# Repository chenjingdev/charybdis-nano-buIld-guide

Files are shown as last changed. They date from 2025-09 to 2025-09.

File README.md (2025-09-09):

# Charybdis(카리브디스) 빌드/제작 가이드

이 레포에 흩어져 있던 가이드를 하나의 문서로 통합했습니다. 아래 목차에서 필요한 섹션을 찾아 읽으시면 됩니다. 원본 개별 문서는 그대로 두되, 상단에 본 README로의 안내 링크를 추가했습니다.

## 목차
- [부품 구매 리스트](#부품-구매-리스트)
- [PCB 설계도 및 출력](#pcb-설계도-및-출력)
  - [엄지/메인 PCB](#엄지메인-pcb)
  - [트랙볼 PCB](#트랙볼-pcb)
  - [C 포트 홀더(컨트롤보드 연결용)](#c-포트-홀더컨트롤보드-연결용)
  - [컨트롤보드(설계 참고)](#컨트롤보드설계-참고)

---

## 부품 구매 리스트

### PCB 주문 (JLCPCB 인보이스 기준)

| 보드 | 버전 | 수량(장) | 단가(USD) | 금액(USD) | 나노 1대 필요(장) |
|---|---|---:|---:|---:|---:|
| [Adapter (C 포트 홀더, 좌/우 세트)](https://github.com/Bastardkb/Elite-C-holder) | v2.1 | 5 | 0.80 | 4.00 | 1 |
| [Right (오른쪽 엄지)](https://github.com/Bastardkb/Charybdis-PCB-thumbs) | v2.01 | 5 | 0.80 | 4.00 | 1 |
| [Left (왼쪽 엄지)](https://github.com/Bastardkb/TBK-Mini-PCB-thumb-cluster) | v2.1 | 5 | 0.82 | 4.10 | 1 |
| [Main (메인)](https://github.com/Bastardkb/Skeletyl-PCB-plate) | v1.3 | 10 | 1.12 | 11.20 | 2 |
| [Sensor SMT (트랙볼 센서)](https://github.com/Bastardkb/charybdis-pmw-3360-sensor-pcb) | - | 5 | 4.74 | 23.68 | 1 |

- Merchandise: $46.98, Shipping: $11.74, Discount: -$9.00, Grand Total: $49.72

#### 출력 두께(주문 기준)
- Main(Y9): 0.8mm
- Left(Y12): 0.8mm
- Right(Y10): 0.8mm
- Adapter(Y4): 1.6mm
- Sensor PCBA(Y3): 1.6mm

### AliExpress 주문

| 부품명 | 옵션 명 | 1패키지당 부품수 | 패키지수량 | 총부품수 | 패키지가격 | 구매가격 | 나노 1대 필요 수량 |
|---|---|---:|---:|---:|---:|---:|---:|
| [SMD 칩 다층 세라믹 캐패시터, 1206 1UF, 50V, 100V, 200V, 105K, X7R, 10% 3216, 20 개 - AliExpress 502](https://www.aliexpress.com/item/1005007350273364.html) | 1206 1UF 50V | 20 | 3 | 60 | ₩1,546 | ₩1,546 | 2 |
| [100pcs SMD 다이오드 0805 SOD-123 1N5819 1N4007 1N4148 SOD123 SOD-323 1206 1N4148WS 1N5819WS B5819WS SOD323 쇼트키 다이오드 - AliExp](https://www.aliexpress.com/item/1005005707644429.html) | 1N4148W SOD123 | 100 | 3 | 300 | ₩1,988 | ₩1,988 | 40 |
| [10/50/100PCS 3.5mm 잭 여성용 오디오 커넥터 4 핀 DIP 헤드폰 잭 소켓 PJ-320A PJ320A 오디오 인터페이스 오디오 잭 검정색 - AliExpress 13](https://www.aliexpress.com/item/1005003111662179.html) | 100 Pcs | 100 | 1 | 100 | ₩8,260 | ₩8,260 | 2 |
| [마이크로 버튼 택트 스위치 Smd 4pin 3x4x2.5mm - 10pcs Smd 4x4x1.5 3mm 4 4 핀 촉각-Aliexpress](https://www.aliexpress.com/item/1005001291287576.html) | 4X4X1.5 Copper | 10 | 10 | 100 | ₩256 | ₩2,560 | 2 |
| [RP2040 Pro 마이크로 라즈베리 PI PICO 개발 보드 듀얼 코어는 Mciro Python을 지원합니다. - AliExpress 502](https://www.aliexpress.com/item/1005005980167753.html) | RP2040 Pro Micro 16M | 1 | 10 | 10 | ₩3,560 | ₩35,600 | 2 |
| [50pcs M1 M1.2 M1.4 M1.6 M2 M2.5 M3 M3.5 M4 GB819 미니 소형 검정색 탄소강 크로스 필립스 플랫 카운터 싱크 헤드 나사 볼트 - AliExpress 13](https://www.aliexpress.com/item/1005003205577232.html) | M3, 8mm | 50 | 10 | 500 | ₩1,155 | ₩11,550 | 3 |
| [50pcs M1 M1.2 M1.4 M1.6 M2 M2.5 M3 M3.5 M4 GB819 미니 소형 검정색 탄소강 크로스 필립스 플랫 카운터 싱크 헤드 나사 볼트 - AliExpress 13](https://www.aliexpress.com/item/1005003205577232.html) | M4, 8mm | 50 | 10 | 500 | ₩1,396 | ₩13,960 | 6 |
| [M2 M3 M4 M5 M6 M8 Brass Heat Insert Nut Double Twill Knurled Hot Melt Injection Embed Thread Inserts Nuts For 3d Printer](https://www.aliexpress.com/item/1005008666672949.html) | Length 5mm, M4 (OD6mm) 30pcs | 30 | 10 | 300 | ₩1,752 | ₩17,520 | 8 |
| [M2 M3 M4 M5 M6 M8 Brass Heat Insert Nut Double Twill Knurled Hot Melt Injection Embed Thread Inserts Nuts For 3d Printer](https://www.aliexpress.com/item/1005008666672949.html) | Length 5mm, M3 (OD5mm) 50pcs | 50 | 10 | 500 | ₩1,938 | ₩19,380 | 8 |
| [PMW3360DM-T2QU 및 LM19-LSI DIP PMW3360 PMW3360DM 센서, 렌즈 LM19 포함, 정품, 로트당 1 개 - AliExpress 502](https://www.aliexpress.com/item/4000904265601.html) | - | 1 | 5 | 5 | ₩9,900 | ₩49,500 | 1 |
| [SMD 픽셀 LED 칩, 개별 주소 지정 가능, 풀 컬러 DC 5V, SK6812 MINI-E RGB (WS2812B 유사), SK6812 3228, 100 개 - AliExpress 36](https://www.aliexpress.com/item/1005007863635868.html) | 100개 × 5 | 100 | 5 | 500 | ₩4,000 | ₩20,000 | 40 |
| [VEICHU 컨베이어 구성 요소 VCN310/311 스테인레스 스틸 라운드 내구성 황소 휠 전송 베어링 롤러 볼 - AliExpress 13](https://www.aliexpress.com/item/1005003066404497.html) | VCN310, 7.5 | 1 | 15 | 15 | ₩1,953 | ₩29,295 | 3 |
| [Perix303 트랙볼, 탈착식 마우스 트랙볼 570, 에르고 드로잉 마우스 볼, 사용자 정의 컴퓨터 게이머 액세서리 선물, 34mm - AliExpress 7](https://www.aliexpress.com/item/1005008358261130.html) | purpel Glossy | 1 | 1 | 1 | ₩28,650 | ₩28,650 | 1 |

### 네이버 주문 (케이블/소모품)

| 품목 | 옵션 명 | 패키지 단위 | 패키지가격 | 배송비 | 1대 필요량 | 1대 비용 |
|---|---|---:|---:|---:|---:|---:|
| [테프론 와이어 AWG26 (네이버 스토어)](https://smartstore.naver.com/spec/products/5320955211) | 단선, 100m, 검정 | 100m | ₩32,000 | ₩3,000 | 4m | ₩1,400 |
| [LT소재 희성납 유연납 RS60](https://smartstore.naver.com/scpmc/products/8570030651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) | 0.6mm, 500g 롤 | 500g | ₩24,000 | ₩3,000 | - | - |
| 필라멘트 (예: PLA) | 1kg 스풀 | 1kg | ₩30,000 | - | 0.33kg | ₩10,000 |

참고: 공식 설명서에서는 리본 케이블을 안내하지만 국내 조달이 어려워 위 테프론 AWG26 단선 케이블로 대체했습니다. 단선은 연선 대비 내구성이 높고 납땜이 쉬워 제작/유지보수에 유리했습니다.

### 스위치(선택 품목)

| 모델/링크 | 패키지 구성 | 패키지가격 | 나노 1대 필요 수량 | 1대 환산(참고) |
|---|---:|---:|---:|---:|
| [TTC Frozen V2 Linear 39g (110pcs)](https://www.aliexpress.com/item/1005008909952057.html) | 110개 | ₩49,990 | 40 | ₩18,178 |

---

### 나노 1대 예상 비용

- 부품 소계(KRW, 스위치 제외): ₩55,309  
  - LED 40개, RP2040 2개, 다이오드 40개, TRRS 커넥터 2개, 베어링/트랙볼 볼, 센서, 나사/인서트 등 포함  
  - 계산식: 각 행의 `(패키지가격 ÷ 1패키지당 부품수) × 나노 1대 필요 수량`
- 케이블 환산(KRW): ₩1,400 (100m/₩35,000 기준, 사용 4m)
- 필라멘트 환산(KRW): ₩10,000 (₩30,000/1kg 기준, 사용 0.33kg)
- 부품+케이블+필라멘트 소계(KRW, 스위치 제외): ₩66,709
- 스위치 환산(참고): ₩18,178 (위 선택 표 기준)
- 스위치 포함시 합계(KRW): ₩84,887
- PCB 소계(USD): $9.40  
  - Adapter $0.80 ×1, Right $0.80 ×1, Left $0.82 ×1, Main $1.12 ×2, Sensor $4.74 ×1

## PCB 설계도 및 출력

PCB 출력 공통 옵션: 거버 파일 업로드 후 색상만 변경. 그 외 옵션은 건드리지 않는 것을 권장합니다.

### 엄지/메인 PCB

- 두께(주문 기준): 메인/엄지 0.8mm, 어댑터/센서 1.6mm. 색상: 검정. 기타 설정은 기본값에서 필수 옵션 2개만 변경.
- 왼쪽(2.1 버전): [TBK-Mini-PCB-thumb-cluster](https://github.com/Bastardkb/TBK-Mini-PCB-thumb-cluster)  
  JLCPCB 청구 기준: $4.10 / 5장
- 오른쪽(2.01 버전): [Charybdis-PCB-thumbs](https://github.com/Bastardkb/Charybdis-PCB-thumbs)  
  JLCPCB 청구 기준: $4.00 / 5장
- 메인(1.3 버전): [Skeletyl-PCB-plate](https://github.com/Bastardkb/Skeletyl-PCB-plate)  
  JLCPCB 청구 기준: $11.20 / 10장
- 특이사항: 5장/10장 가격차가 크지 않음. 부품 확정 후 한 번에 여러 장 출력해 두고두고 사용하는 것을 권장.

### 트랙볼 PCB

- 설계도: [charybdis-pmw-3360-sensor-pcb Releases](https://github.com/Bastardkb/charybdis-pmw-3360-sensor-pcb/releases)  
- 카리브디스 공식 홈페이지 제공 설계도 latest 버전.
- 주의사항:  
  - bom.csv에 마우스 센서(U1001)와 커넥터(J1001) 부품 목록이 있으나, 실제 PCB 뽑을 때는 필요 없으므로 업로드 전 삭제(미삭제 시 오류).  
  - position.csv는 파일명을 cpl.csv로 변경 후 업로드해야 오류가 나지 않음.  
  - 출력 옵션은 거버 파일 업로드 후 색상만 변경.  
- 가격: $23.68 / 5장 (JLCPCB 청구서). BOM 실장 포함된 제품 구성이라 상대적으로 고가.

### C 포트 홀더(컨트롤보드 연결용)

- 설계도(Elite-C holder): [Releases](https://github.com/Bastardkb/Elite-C-holder/releases)  
  현재 레포 내 기준 버전: 2.1  
- 출력 옵션: 거버 파일 업로드 후 색상만 변경.

참고: 제공되는 거버는 좌/우 홀더가 한 장(패널)으로 합쳐진 형태입니다. 즉, 한 장 주문으로 좌/우 한 세트를 구성할 수 있습니다.

### 컨트롤보드(설계 참고)(알리구매로대체함)

- Splinky(공식 설계도, latest): [bk3.2 Releases](https://github.com/Bastardkb/Splinky/releases/tag/bk3.2)  
- 비고: JLCPCB 생산 시 일부 부품 부재로 생산이 막힐 수 있음(부품 없어서 알리 완제품으로 구매).

---

본 README는 참고용으로 제공됩니다. 링크/가격/버전은 수시로 변경될 수 있으며, 최신 정보는 각 링크의 공식 문서를 확인하세요.

---

### 완성품 사진

완성품 1
완성품 2
완성품 3
완성품 4

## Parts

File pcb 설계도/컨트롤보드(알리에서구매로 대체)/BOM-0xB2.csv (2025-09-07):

Comment | Designator | Footprint | LCSC
1k | R1,R3,R8 | R_0402_1005Metric | C11702
B5817 | D2 | D_SOD-323 | C123899
LED | D1 | LED_0402_1005Metric | C130719
100n | C10,C11,C12,C13,C14,C7,C8,C9 | C_0402_1005Metric | C1525
15p | C3,C4 | C_0402_1005Metric | C1548
1µ | C1,C2 | C_0603_1608Metric | C19666
RP2040 | U1 | QFN-56-1EP_7x7mm_P0.4mm_EP3.2x3.2mm | C2040
Crystal_GND24 | Y1 | Crystal_SMD_2520-4Pin_2.5x2.0mm | C2149204
USB_C_Receptacle_USB2.0 | J1 | GT-USB-7014C | C963373
27 | R6,R7 | R_0402_1005Metric | C25100
10k | R11,R2,R9 | R_0402_1005Metric | C25744
5.1k | R10,R4,R5 | R_0402_1005Metric | C25905
SW_Push | SW1 | SW_SPST_CK_KXT3 | C319433
GD25Q80CEIGR | U2 | USON-8-1EP_3x2mm_P0.5mm_EP0.25x1.65mm | C395484
1µ | C5,C6 | C_0402_1005Metric | C52923
Polyfuse | F1 | Fuse_0603_1608Metric | C69679
XC6210B332MR-G | U3 | SOT-23-5 | C82942
FerriteBead_Small | FB1 | L_0603_1608Metric | C98288

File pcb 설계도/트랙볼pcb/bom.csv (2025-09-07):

Designator | Footprint | Quantity | Value | LCSC Part #
C1001 | 0603 | 1 | 4.7uF | C19666
C1002, C1005 | 0603 | 2 | 1uF | C15849
IC1001 | SOT-23-5_HandSoldering | 1 | AP7335-WG-7 | C460382
J1002 | FPC-SMD_FPC05012-09200-.5mm | 1 | jst connector | C479750
R1001, R1004 | 0603 | 2 | 10k | C25804
R1002 | 0603 | 1 | 39 | C23154
R1003 | 0603 | 1 | 15k | C22809

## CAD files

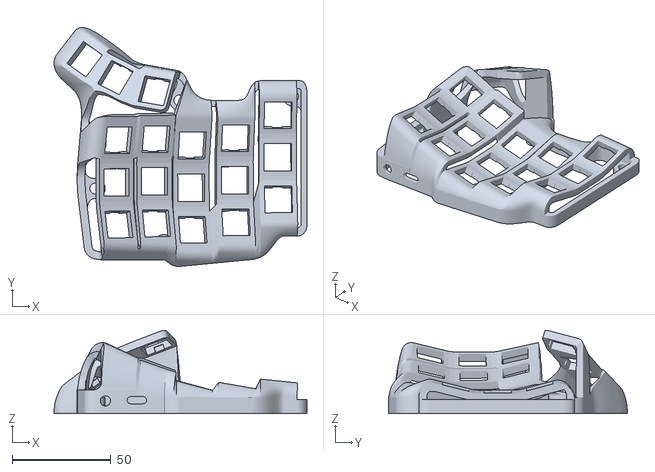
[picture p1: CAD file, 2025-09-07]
3d프린터 설계도/case(left)/case_v4_103.stl
128.0 x 120.9 x 42.0

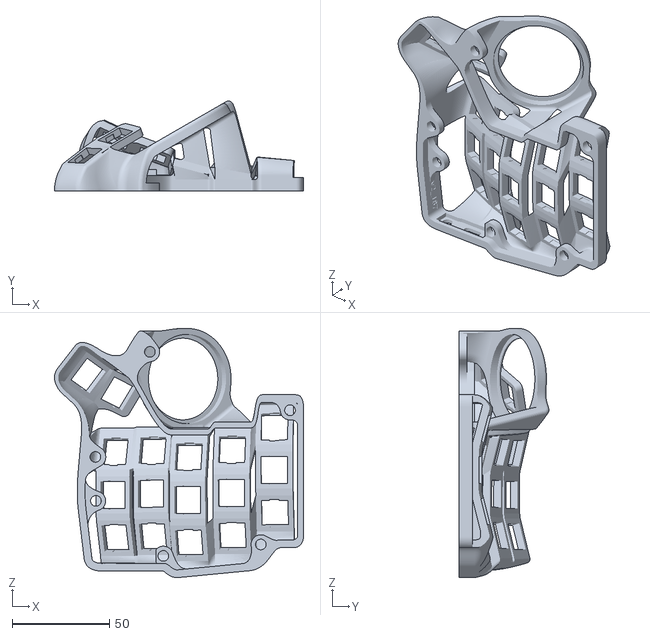
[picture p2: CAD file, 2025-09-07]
3d프린터 설계도/case(right)/charybdisnano_v2_v187.stl
128.0 x 46.2 x 128.1

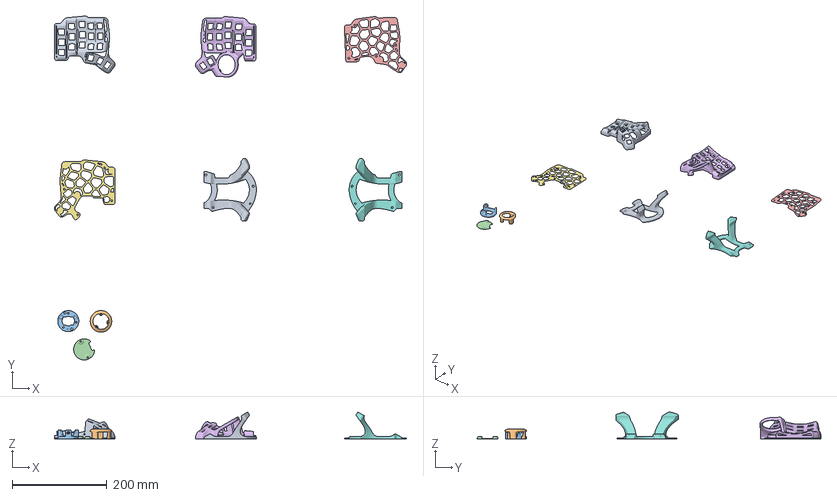
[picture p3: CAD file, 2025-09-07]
3d프린터 설계도/case_v4_103.3mf
744.0 x 727.1 x 56.4 mm
case_v4_103.stl
Ball_cover_resin_5mm.stl
veichu.stl
sensor_cover_v51.stl
plate_v4_103.stl
charybdisnano_v2_v187.stl
alien_v2_185.stl
Body14.stl x 2

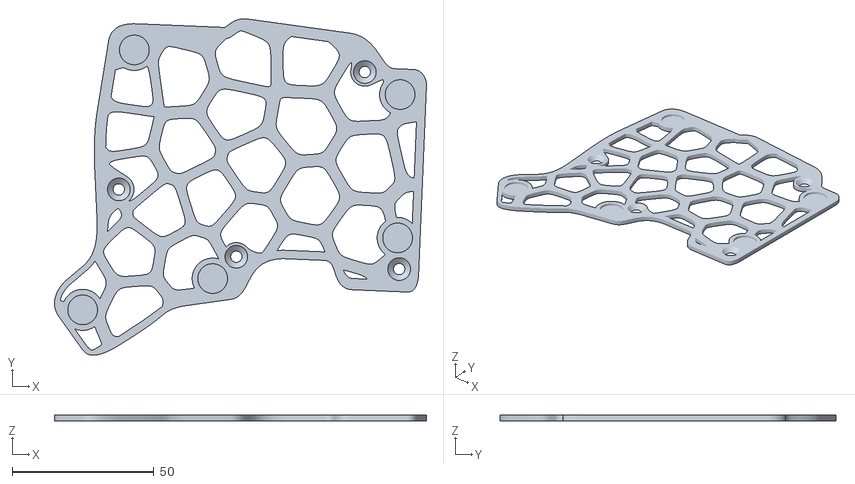
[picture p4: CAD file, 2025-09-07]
3d프린터 설계도/plates(left)/plate_v4_103.stl
131.3 x 118.7 x 2.00

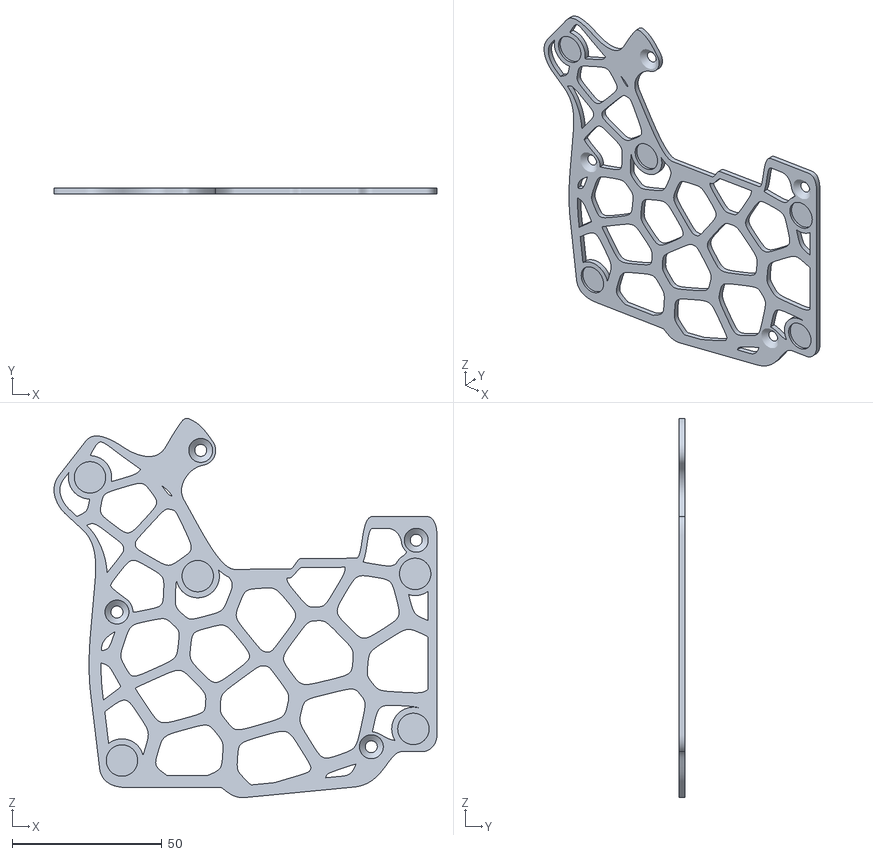
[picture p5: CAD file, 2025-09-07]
3d프린터 설계도/plates(right)/alien_v2_185.stl
128.0 x 2.00 x 126.7

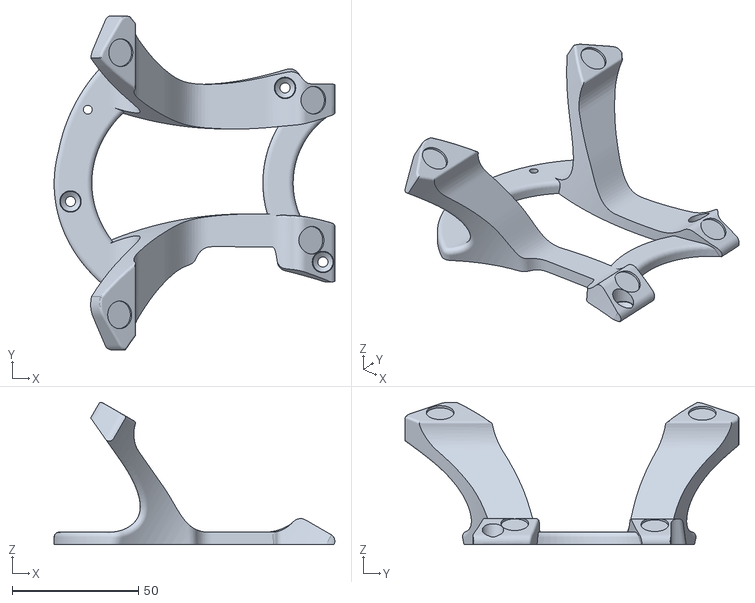
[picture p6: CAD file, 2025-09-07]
3d프린터 설계도/tent(left)/Body14.stl
111.2 x 132.3 x 56.4

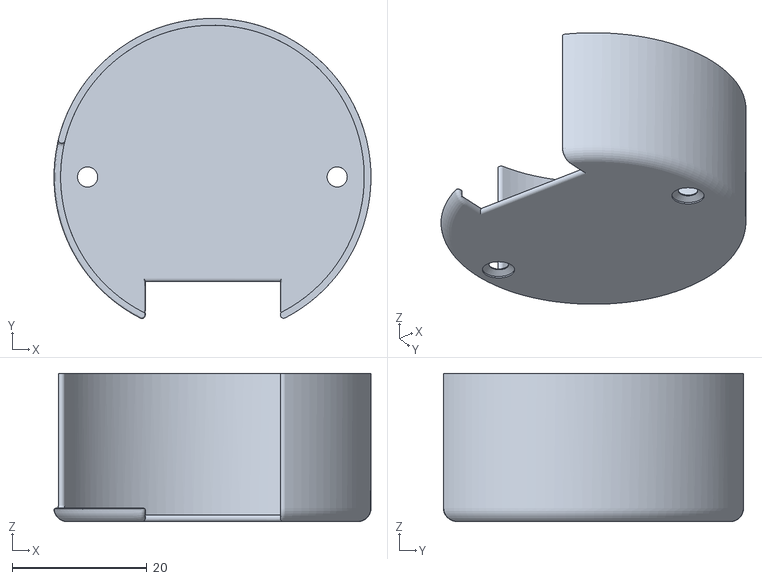
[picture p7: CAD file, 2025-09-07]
3d프린터 설계도/센서부/Sensor_cover.stl
47.0 x 44.5 x 22.0

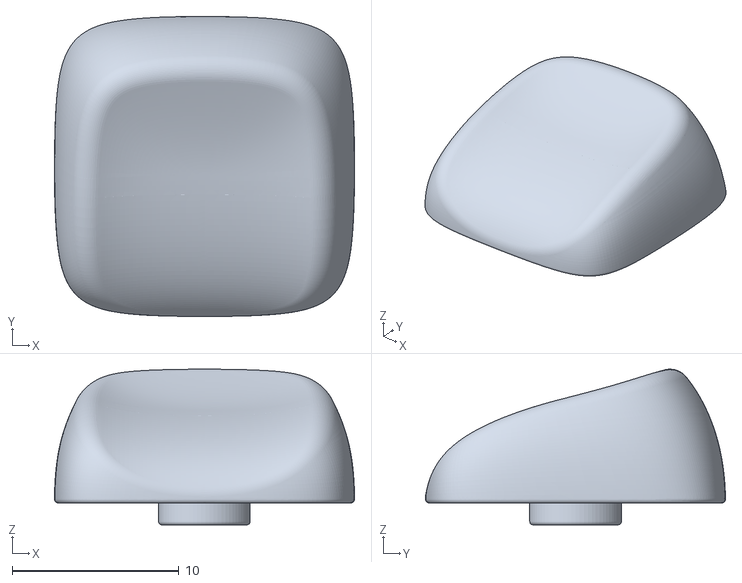
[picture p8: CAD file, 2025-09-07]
3d프린터 설계도/키캡/MX_Stem_MX_Size_Saddle_Tilted.stl
18.0 x 18.0 x 9.34

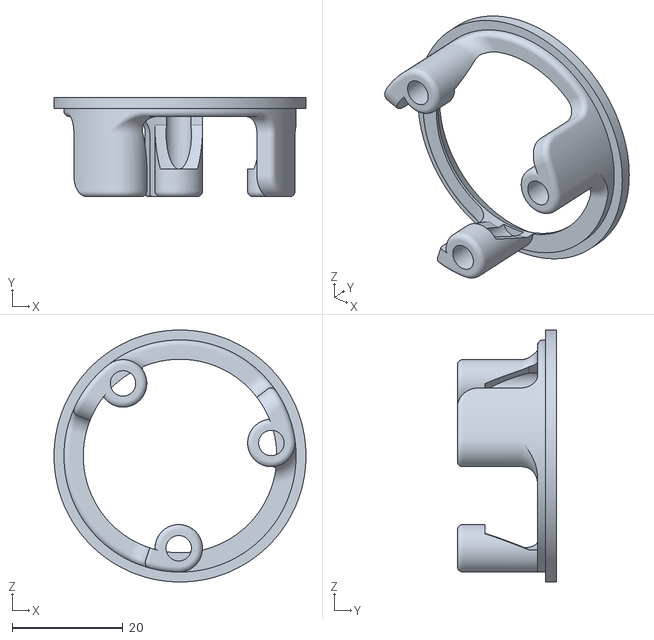
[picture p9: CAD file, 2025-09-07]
3d프린터 설계도/센서부/adapter_v2_top_v75.stl
45.6 x 18.0 x 45.6

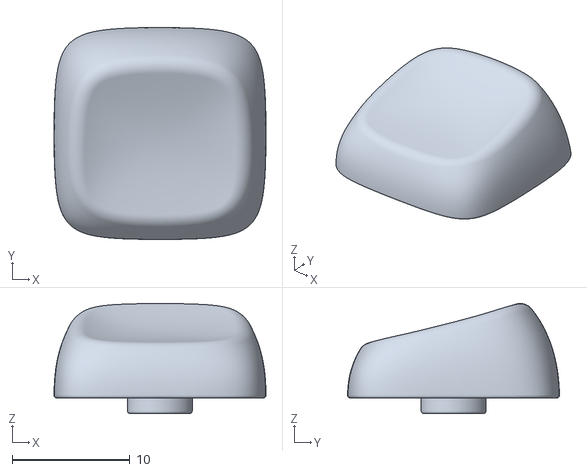
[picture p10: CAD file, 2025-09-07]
3d프린터 설계도/키캡/MX_Stem_MX_Size_Normal_Tilted.stl
18.0 x 18.0 x 9.34

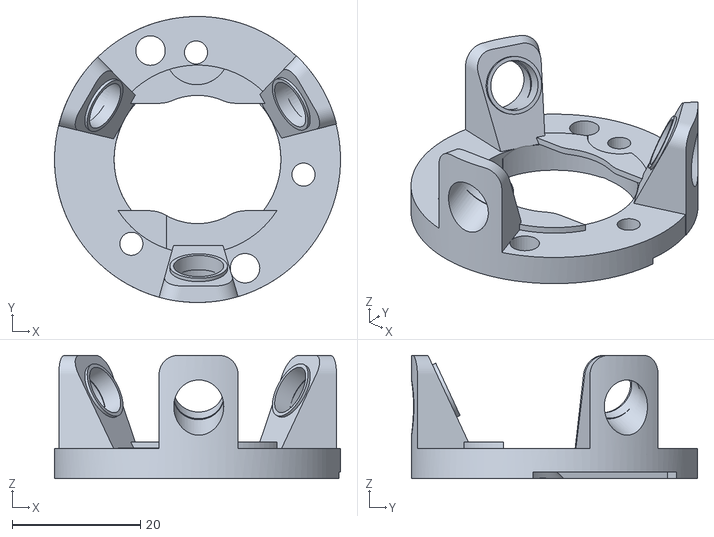
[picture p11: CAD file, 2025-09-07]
3d프린터 설계도/센서부/veichu.stl
44.6 x 44.6 x 19.2

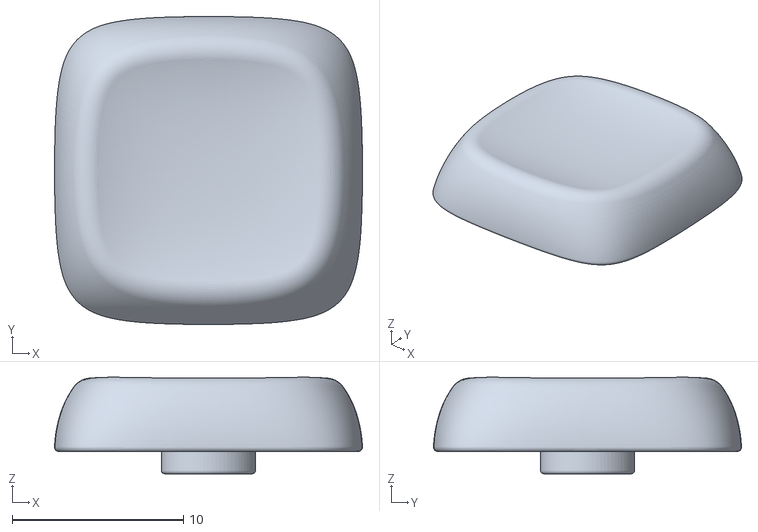
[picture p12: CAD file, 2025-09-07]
3d프린터 설계도/키캡/MX_Stem_MX_Size_Normal.stl
18.0 x 18.0 x 5.64

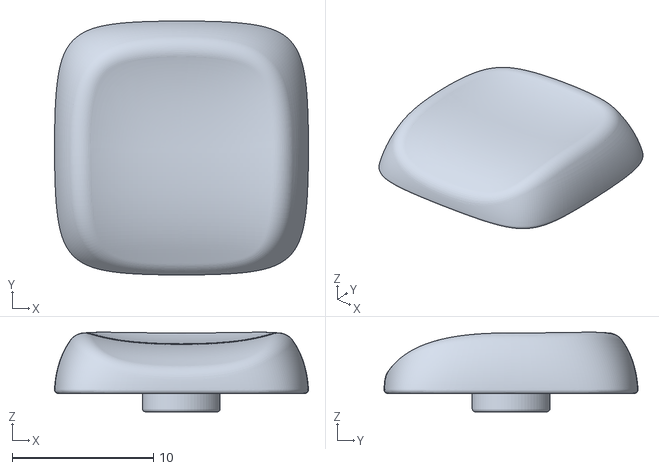
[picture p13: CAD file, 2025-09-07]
3d프린터 설계도/키캡/MX_Stem_MX_Size_Thumb.stl
18.0 x 18.0 x 5.64

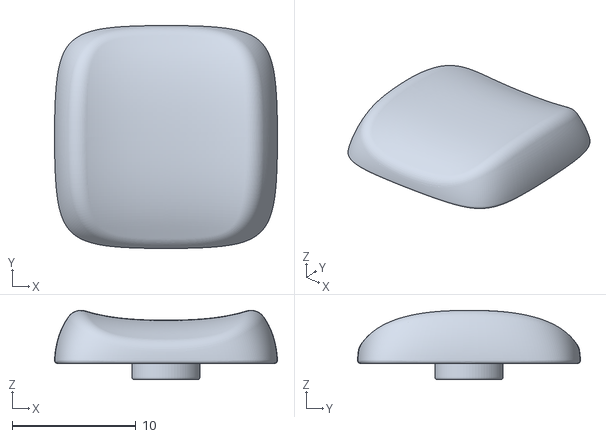
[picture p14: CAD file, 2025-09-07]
3d프린터 설계도/키캡/MX_Stem_MX_Size_Saddle.stl
18.0 x 18.0 x 5.59

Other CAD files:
3d프린터 설계도/tent(right)/Body14.stl
3d프린터 설계도/키캡/MX_Stem_MX_Size_Normal_Homing.stl
3d프린터 설계도/키캡/MX_Stem_MX_Size_Saddle_Homing.stl

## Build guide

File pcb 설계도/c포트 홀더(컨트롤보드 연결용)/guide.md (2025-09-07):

> 참고: 이 문서는 레포 루트의 `README.md`로 통합되었습니다. 최신 내용은 `../../README.md`를 확인하세요.

https://ko.aliexpress.com/item/1005001304569553.html?spm=a2g0s.9042311.0.0.27424c4dDwgcp7&gatewayAdapt=glo2kor

4x4x1.5 버튼 구매

https://github.com/Bastardkb/Elite-C-holder/releases
pcb설계도 링크(현재 버전은 2.1)

pcb출력 옵션은 가버파일 올리고 색상만 바꿈.(다른거 건들지 말것)

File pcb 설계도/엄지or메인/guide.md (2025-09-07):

> 참고: 이 문서는 레포 루트의 `README.md`로 통합되었습니다. 최신 내용은 `../../README.md`를 확인하세요.

두께는 전부 0.8, 검은색 옵션 2개만 변경

왼쪽(2.1버전)
https://github.com/Bastardkb/TBK-Mini-PCB-thumb-cluster
4.1달러 5장

오른쪽(2.01 버전)
https://github.com/Bastardkb/Charybdis-PCB-thumbs
4달러 5장

메인(1.3 버전)
https://github.com/Bastardkb/Skeletyl-PCB-plate
11.2달러 10장

특이사항: 5장 10장 가격차이 얼마 안남.
부품 확정되면 한번에 여러장 뽑고 두고두고 만드는게 좋을듯

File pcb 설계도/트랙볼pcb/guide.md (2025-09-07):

> 참고: 이 문서는 레포 루트의 `README.md`로 통합되었습니다. 최신 내용은 `../../README.md`를 확인하세요.

https://github.com/Bastardkb/charybdis-pmw-3360-sensor-pcb/releases

카리브디스 공식 홈페이지에서 제공하는 설계도 latest버전임

bom.csv에서 마우스 센서랑 커넥터 부품 목록이 적혀 있는데(U1001과 J1001) 실제 pcb뽑을 땐 필요 없기 때문에 실제 업로드 할 땐 지우고 업로드 해야함.(안그럼 오류남)

position.csv는 파일명 cpl.csv로 이름 변경하고 올려야 오류 안남.

pcb출력 옵션은 가버파일 올리고 색상만 바꿈.(다른거 건들지 말것)

23.68달러 / 5장

해당 제품은 미세부품(bom 파일)까지 조합된 제품이라 가격 좀 됨.

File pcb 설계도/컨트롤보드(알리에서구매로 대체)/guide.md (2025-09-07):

> 참고: 이 문서는 레포 루트의 `README.md`로 통합되었습니다. 최신 내용은 `../../README.md`를 확인하세요.

https://github.com/Bastardkb/Splinky/releases/tag/bk3.2

카리브디스 공식 홈페이지에서 제공하는 설계도 latest버전임

jlcpcb에서 출력하려고해도, 부품 없는게 있어서 생산이 안됨. 호환되는 부품 알아서 공부해서 꼽을사람 이걸로 꼽아서 사도 됨.

근데 비용보니 그냥 알리에서 완제품 사는게 가성비임.

알리 링크
https://ko.aliexpress.com/item/1005005980167753.html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

pcb출력 옵션은 가버파일 올리고 색상만 바꿈.(다른거 건들지 말것)

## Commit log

2025-09-07 chore: initial import and consolidate guides into README
    [BOM-0xB2.csv, Body14.stl, MX_Stem_MX_Size_Normal.stl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]
2025-09-07 docs(README): remove 3D printing section and TOC; update ribbon cable link to Naver SmartStore
2025-09-07 docs(README): add PCB items to parts list table
2025-09-07 docs(README): fill per-build quantities for typical Charybdis Nano build (diodes, switches, PCBs, bearings, screws, spacers, connectors)
2025-09-07 docs(README): add items from screenshots (heat inserts, SK6812 Mini-E, tact switch, 330R resistor, MJ310 bearing, Perix303 ball)
2025-09-07 docs(README): update PCB prices to match JLCPCB invoice (left .10/5, right .00/5, main 1.20/10, sensor 3.68/5, adapter .00/5)
2025-09-07 docs(README): fix markdown table rendering by moving totals to separate section; update 330Ω resistor row
2025-09-08 docs(README): update AliExpress table from CSV with titles, options, and prices; split PCB vs Ali orders; cleanup duplicates
2025-09-08 docs(README): 업데이트된 출력 두께 정보 추가 및 컨트롤보드 설명 수정
2025-09-08 docs(README): PCB 및 AliExpress 주문 테이블에 나노 필요 수량 추가 및 링크 수정
2025-09-08 docs(README): 네이버 주문 및 스위치 선택 품목 추가, 나노 1대 예상 비용 계산식 포함
2025-09-08 chore: add .gitignore for .DS_Store; remove tracked .DS_Store; delete 가이드 folder
2025-09-08 docs(README): 완성품 사진 섹션 추가
2025-09-09 Revise PCB order section in README
    Removed redundant text and clarified the PCB order section.
